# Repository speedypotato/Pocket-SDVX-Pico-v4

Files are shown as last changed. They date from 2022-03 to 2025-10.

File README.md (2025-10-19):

# Pocket-SDVX-Pico-v4
Pocket SDVX Pico v4 source files, production files, and documentation

This work is licensed under a Creative Commons Attribution-NonCommercial-ShareAlike 4.0 International License.  中国人，我在看你们。

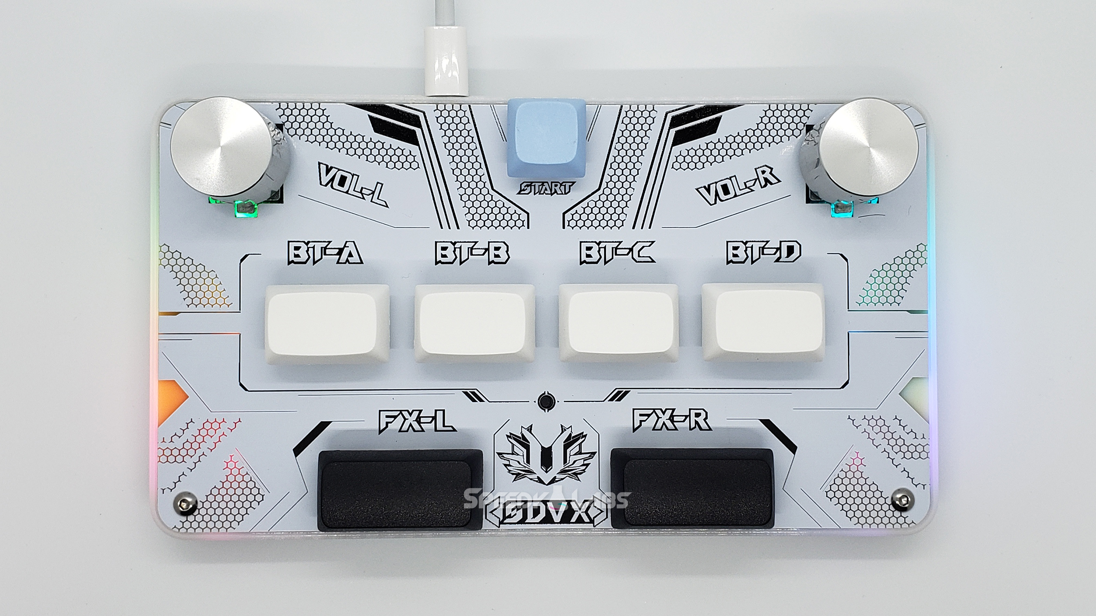
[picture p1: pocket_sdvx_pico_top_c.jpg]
Pocket SDVX Pico v4


Although I won't be selling this particular version anymore, I have plans to sell updated designs soon.  Join the discord for discussion and support! https://discord.gg/MmuKd73XbY . I also now have a storefront! https://www.speedylabs.us/

## Parts Required:
- JLCPCB parts (Boards are 180 mm*100 mm, white PCB color, remove order number[specify a location]):
    - 1x Pocket-SDVX-Pico-Plate-v4-2 (MOQ 5)
    - 1x Pocket-SDVX-Pico-v4-3 + SMT Assembly (MOQ 5)
        - SMT Assemble the top side.  There should be 9 unique parts.
- McMaster parts:
    - 4x Feet - 8884T13
    - 4x M3 Lock Nut - 90576A102
    - 4x M3x12 Screw - 92095A183 
    - 4x No.6 1/8" Nylon Spacer - 94639A507 
- Mouser parts:
    - 2x 2U Stabilizer - 540-G99-0224
    - 2x Encoder - PEC16-4015F-N0024
- 1x Raspberry Pi Pico
- XDA Keycap Set https://www.speedylabs.us/product/pocket-sdvx-keycaps/
    - 1x 1u, 4x 1.5u, 2x 2u
- 2x 22mm Knob https://www.speedylabs.us/product/pocket-sdvx-aluminum-knob/
- 7x Gateron Yellow Switches (GATERON KS-9 or any switch with LED cutout)
- 7x Gateron Hotswap Sockets
- 1x 3D printed case, White PETG https://www.speedylabs.us/product/pocket-sdvx-pico-case/

[Pocket SDVX Pico v4 Quick Start Guide](https://docs.google.com/document/d/1lTzADQI5E5vRpHBv-0IfLbDSh2zEKCUAdh5BqFhex2I/edit?usp=sharing)  
[Kit Assembly Guide](https://docs.google.com/document/d/1bsWk7fmLKUGv5YgQknoNQcy0RX3fi5gCZRvfOJAa-P0/)

## Addendum
As promised many months ago, Speedy Labs' most popular product is now open sourced.  Pocket-SDVX-Pico v4 is my second PCB, and therefore everything's a little bit sloppy.  Nevertheless, everything here is functional and has been self-learned online along with the help of the community.  Thanks for all the support!

FYI I should probably let everyone know the most common defects I've received:
- RGB LEDs dead or not soldered properly
- Extra Aux Button wobbly/non-functional/misaligned
- Smudged Silkscreen

There's probably a 5% chance of this happening according to my statistics.  Nothing you can do about it aside from repairing it yourself.

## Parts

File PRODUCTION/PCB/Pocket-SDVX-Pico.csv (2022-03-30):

Comment | Designator | Footprint | LCSC
10nF | C1,C2,C3,C4 | Capacitor_SMD:C_0603_1608Metric | C57112
PEC16-4015F-N0024 | E1,E2 | PEC16-4015F-N0024:PEC16-4015F-N0024-millmax
WS2812B-4020 | LED1,LED2,LED3,LED4,LED5,LED6,LED7,LED8,LED9,LED10 | WS2812B-4020:WS2812B-4020 | C965557
MX-LED-B | MX1 | MX_Only:MXOnly-1.5U-Hotswap-LED-SMD | C440444
MX-LED | MX2,MX3,MX4,MX5 | MX_Only:MXOnly-1.5U-Hotswap-LED-SMD | C26545
MX-LED-R | MX6,MX7 | MX_Only:MXOnly-1.5U-Hotswap-LED-SMD | C440441
220R | R1,R2,R3,R4,R5,R6,R7,R10 | Resistor_SMD:R_0603_1608Metric | C22962
5K1 | R8,R9 | Resistor_SMD:R_0603_1608Metric | C23186
KAN4542-0701C | SW1 | K2-1102SP-C4SC-04:KAN4542-0701C | C231726
Pico | U1 | MCU_RaspberryPi_and_Boards:RPi_Pico_SMD_TH
918-418K2023S40001 | USB1 | Type-C:HRO-TYPE-C-31-M-12-Assembly | C167321

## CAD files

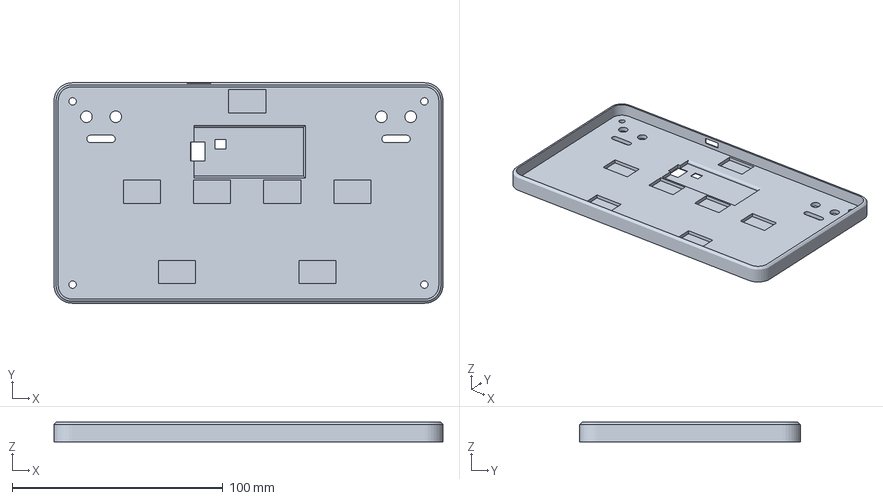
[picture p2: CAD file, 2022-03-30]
PRODUCTION/CASE/Pocket-SDVX-Pico-Case_v4-3.3MF
184.7 x 104.7 x 9.28 mm

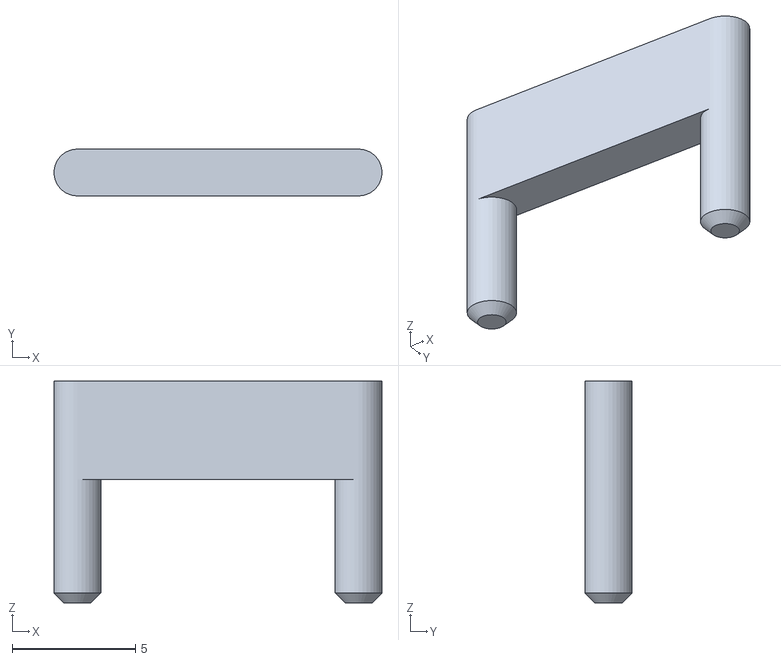
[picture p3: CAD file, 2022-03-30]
PRODUCTION/TOOL/pico_tool_v3.STL
13.3 x 1.90 x 9.00

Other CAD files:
SOURCE/CASE/Pocket-SDVX-Pico-Case.SLDPRT
SOURCE/TOOL/pico_tool_v3.SLDPRT

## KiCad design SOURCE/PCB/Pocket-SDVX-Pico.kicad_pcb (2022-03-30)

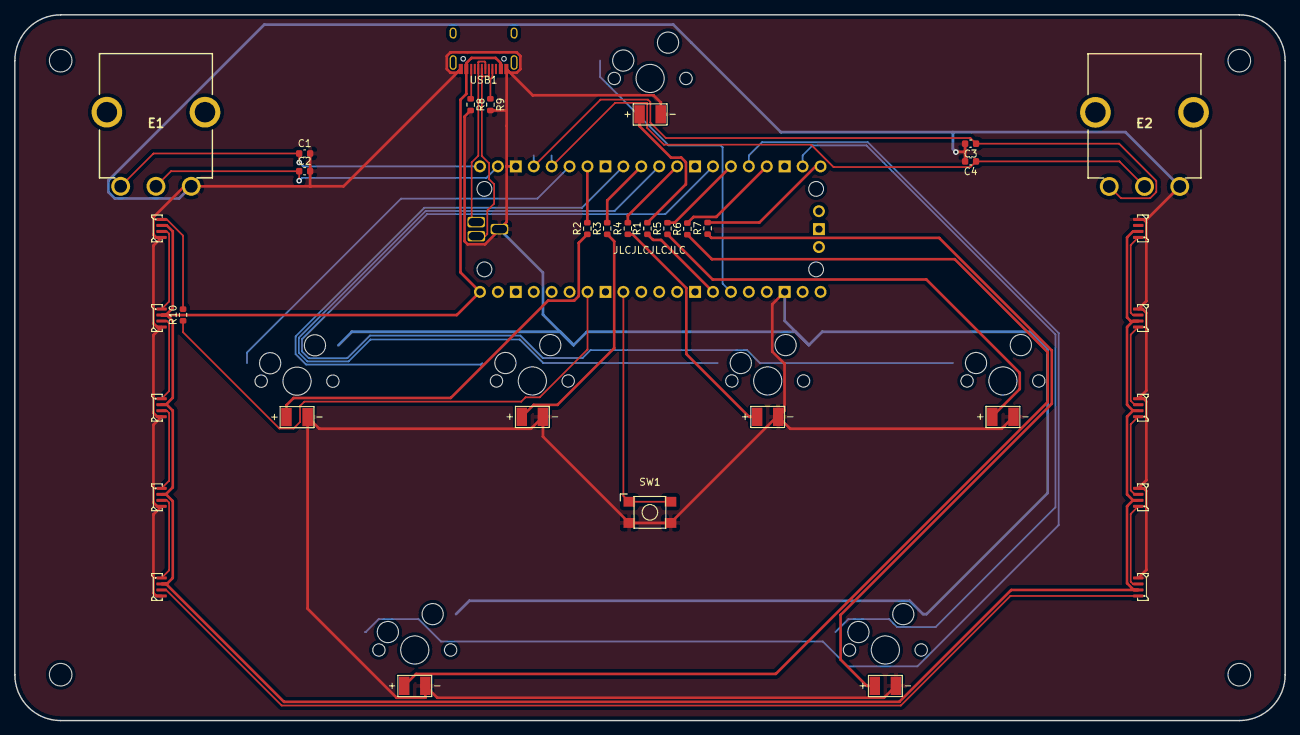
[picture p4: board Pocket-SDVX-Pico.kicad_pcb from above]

Board: 2 copper layers, 180.0 x 100.0 mm, 36 parts (1 on the bottom side), 43 nets.

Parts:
C1, C2, C3, C4: 10nF; C_0603_1608Metric
E1, E2: PEC16-4015F-N0024; PEC16-4015F-N0024-millmax
LED1, LED2, LED3, LED4, LED5, LED6, LED7, LED8, LED9, LED10: WS2812B-4020
MX1: MX-LED-B; MXOnly-1.5U-Hotswap-LED-SMD
MX2, MX3, MX4, MX5: MX-LED; MXOnly-1.5U-Hotswap-LED-SMD
MX6, MX7: MX-LED-R; MXOnly-1.5U-Hotswap-LED-SMD
R1, R2, R3, R4, R5, R6, R7, R10: 220R; R_0603_1608Metric
R8, R9: 5K1; R_0603_1608Metric
SW1: KAN4542-0701C
U1: Pico; RPi_Pico_SMD_TH
USB1: HRO-TYPE-C-31-M-12; HRO-TYPE-C-31-M-12-Assembly

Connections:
+5V: LED1.2, LED2.2, LED3.2, LED4.2, LED5.2, LED6.2, LED7.2, LED8.2, LED9.2, LED10.2, U1.40, USB1.2, USB1.11
GND: C1.2, C2.2, C3.2, C4.2, E1.C1, E2.C1, LED1.4, LED2.4, LED3.4, LED4.4, LED5.4, LED6.4, LED7.4, LED8.4, LED9.4, LED10.4, MX1.2, MX1.4, MX2.2, MX2.4, MX3.2, MX3.4, MX4.2, MX4.4, MX5.2, MX5.4, MX6.2, MX6.4, MX7.2, MX7.4, R8.2, R9.2, SW1.3, SW1.4, U1.3, U1.23, U1.TP1, USB1.1, USB1.12
unnamed: C1.1, E1.A1, U1.1
unnamed: C2.1, E1.B1, U1.2
unnamed: C3.1, E2.A1, U1.4
unnamed: C4.1, E2.B1, U1.5
unnamed: LED1.1, R10.2
unnamed: LED1.3, LED2.1
unnamed: LED2.3, LED3.1
unnamed: LED3.3, LED4.1
unnamed: LED4.3, LED5.1
unnamed: LED5.3, LED6.1
unnamed: LED6.3, LED7.1
unnamed: LED7.3, LED8.1
unnamed: LED8.3, LED9.1
unnamed: LED9.3, LED10.1
unnamed: MX1.1, U1.26
unnamed: MX1.3, R1.1
unnamed: MX2.1, U1.6
unnamed: MX2.3, R2.1
unnamed: MX3.1, U1.9
unnamed: MX3.3, R3.1
unnamed: MX4.1, U1.11
unnamed: MX4.3, R4.1
unnamed: MX5.1, U1.14
unnamed: MX5.3, R5.1
unnamed: MX6.1, U1.16
unnamed: MX6.3, R6.1
unnamed: MX7.1, U1.19
unnamed: MX7.3, R7.1
unnamed: R1.2, U1.27
unnamed: R2.2, U1.7
unnamed: R3.2, U1.10
unnamed: R4.2, U1.12
unnamed: R5.2, U1.15
unnamed: R6.2, U1.17
unnamed: R7.2, U1.20
unnamed: R8.1, USB1.10
unnamed: R9.1, USB1.4
unnamed: R10.1, U1.34
unnamed: SW1.1, SW1.2, U1.32
unnamed: U1.TP2, USB1.5, USB1.7
unnamed: U1.TP3, USB1.6, USB1.8

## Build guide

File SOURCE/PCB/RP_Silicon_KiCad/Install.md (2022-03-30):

# Install KiCad libraries

## Manage Symbol Libraries

Accessed from the Preferences menu, add a new line with the +, give it a name and use the folder icon to point to the directory/folder where you have KiCadLibraries.

Manage Symbol Libraries screen shot


## Manage Footprint Libraries

Ditto! Accessed from the Preferences menu, add a new line with the +, give it a name and use the folder icon to point to the directory/folder where you have KiCadLibraries.

Manage Footprint Libraries screen shot
